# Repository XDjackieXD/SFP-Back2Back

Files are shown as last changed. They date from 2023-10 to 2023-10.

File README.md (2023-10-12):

# SFP+ Back2Back

This is a simple board to connect two SFP/SFP+ modules together.

So far it has only been tested with 10G fiber transceivers.
While it should work with other 1G and 10G (and maybe even 25G) modules and DACs too, I have not tested it with those (and I know that DACs tend to be more of an issue with such passive adapters/extenders).

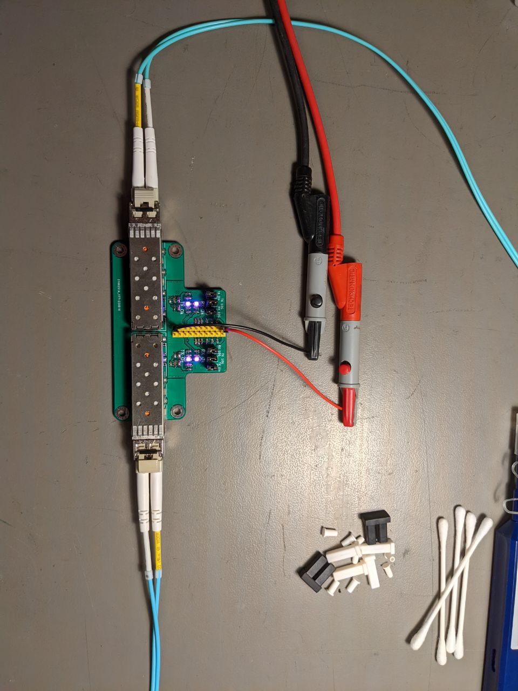
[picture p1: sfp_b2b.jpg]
The SFP+ Back2Back board connected to a power supply and two multimode SFP+ transceivers SFP+ Back2Back


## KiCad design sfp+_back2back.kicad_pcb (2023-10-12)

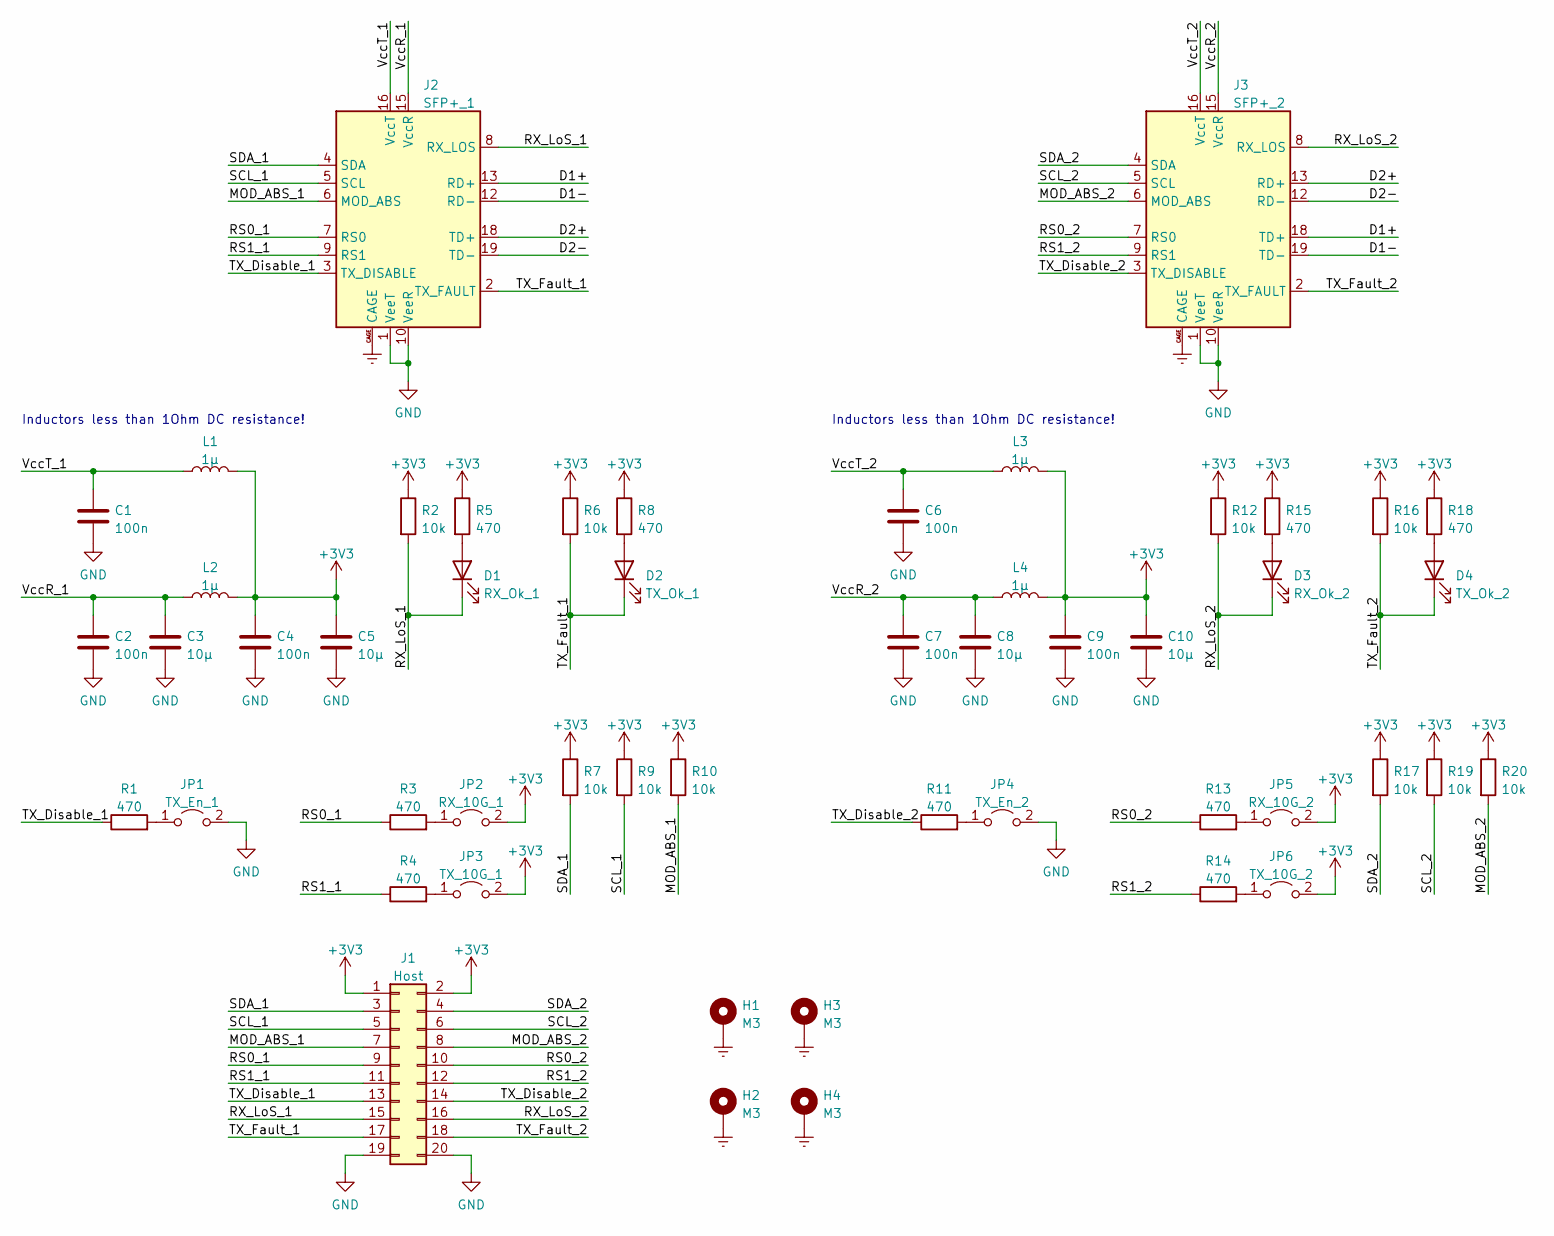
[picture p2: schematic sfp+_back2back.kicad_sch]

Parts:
C1, C2, C4, C6, C7, C9: 100n; C_0603_1608Metric_Pad1.08x0.95mm_HandSolder
C3, C5, C8, C10: 10µ; C_0805_2012Metric_Pad1.18x1.45mm_HandSolder
D1: RX_Ok_1; LED_0805_2012Metric_Pad1.15x1.40mm_HandSolder
D2: TX_Ok_1; LED_0805_2012Metric_Pad1.15x1.40mm_HandSolder
D3: RX_Ok_2; LED_0805_2012Metric_Pad1.15x1.40mm_HandSolder
D4: TX_Ok_2; LED_0805_2012Metric_Pad1.15x1.40mm_HandSolder
H1, H2, H3, H4: M3; MountingHole_3.2mm_M3_Pad_Via
J1: Host; PinHeader_2x10_P2.54mm_Vertical
J2: SFP+_1; Connector_SFP_and_Cage
J3: SFP+_2; Connector_SFP_and_Cage
JP1: TX_En_1; PinHeader_1x02_P2.54mm_Vertical
JP2: RX_10G_1; PinHeader_1x02_P2.54mm_Vertical
JP3: TX_10G_1; PinHeader_1x02_P2.54mm_Vertical
JP4: TX_En_2; PinHeader_1x02_P2.54mm_Vertical
JP5: RX_10G_2; PinHeader_1x02_P2.54mm_Vertical
JP6: TX_10G_2; PinHeader_1x02_P2.54mm_Vertical
L1, L2, L3, L4: 1µ; L_0805_2012Metric_Pad1.15x1.40mm_HandSolder
R1, R3, R4, R5, R8, R11, R13, R14, R15, R18: 470; R_0603_1608Metric_Pad0.98x0.95mm_HandSolder
R2, R6, R7, R9, R10, R12, R16, R17, R19, R20: 10k; R_0603_1608Metric_Pad0.98x0.95mm_HandSolder

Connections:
+3V3: C4.1, C5.1, C9.1, C10.1, J1.1, J1.2, JP2.2 (B), JP3.2 (B), JP5.2 (B), JP6.2 (B), L1.2, L2.2, L3.2, L4.2, R2.1, R5.1, R6.1, R7.1, R8.1, R9.1, R10.1, R12.1, R15.1, R16.1, R17.1, R18.1, R19.1, R20.1
/D1+: J2.13 (RD+), J3.18 (TD+)
/D1-: J2.12 (RD-), J3.19 (TD-)
/D2+: J2.18 (TD+), J3.13 (RD+)
/D2-: J2.19 (TD-), J3.12 (RD-)
/MOD_ABS_1: J1.7, J2.6 (MOD_ABS), R10.2
/MOD_ABS_2: J1.8, J3.6 (MOD_ABS), R20.2
/RS0_1: J1.9, J2.7 (RS0), R3.1
/RS0_2: J1.10, J3.7 (RS0), R13.1
/RS1_1: J1.11, J2.9 (RS1), R4.1
/RS1_2: J1.12, J3.9 (RS1), R14.1
/RX_LoS_1: D1.1 (K), J1.15, J2.8 (RX_LOS), R2.2
/RX_LoS_2: D3.1 (K), J1.16, J3.8 (RX_LOS), R12.2
/SCL_1: J1.5, J2.5 (SCL), R9.2
/SCL_2: J1.6, J3.5 (SCL), R19.2
/SDA_1: J1.3, J2.4 (SDA), R7.2
/SDA_2: J1.4, J3.4 (SDA), R17.2
/TX_Disable_1: J1.13, J2.3 (TX_DISABLE), R1.1
/TX_Disable_2: J1.14, J3.3 (TX_DISABLE), R11.1
/TX_Fault_1: D2.1 (K), J1.17, J2.2 (TX_FAULT), R6.2
/TX_Fault_2: D4.1 (K), J1.18, J3.2 (TX_FAULT), R16.2
/VccR_1: C2.1, C3.1, J2.15 (VccR), L2.1
/VccR_2: C7.1, C8.1, J3.15 (VccR), L4.1
/VccT_1: C1.1, J2.16 (VccT), L1.1
/VccT_2: C6.1, J3.16 (VccT), L3.1
Earth: H1.1, H2.1, H3.1, H4.1, J2.CAGE, J3.CAGE
GND: C1.2, C2.2, C3.2, C4.2, C5.2, C6.2, C7.2, C8.2, C9.2, C10.2, J1.19, J1.20, J2.1 (VeeT), J2.10 (VeeR), J2.11 (VeeR), J2.14 (VeeR), J2.17 (VeeT), J2.20 (VeeT), J3.1 (VeeT), J3.10 (VeeR), J3.11 (VeeR), J3.14 (VeeR), J3.17 (VeeT), J3.20 (VeeT), JP1.2 (B), JP4.2 (B)
unnamed: D1.2 (A), R5.2
unnamed: D2.2 (A), R8.2
unnamed: D3.2 (A), R15.2
unnamed: D4.2 (A), R18.2
unnamed: JP1.1 (A), R1.2
unnamed: JP2.1 (A), R3.2
unnamed: JP3.1 (A), R4.2
unnamed: JP4.1 (A), R11.2
unnamed: JP5.1 (A), R13.2
unnamed: JP6.1 (A), R14.2

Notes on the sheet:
Inductors less than 1Ohm DC resistance!

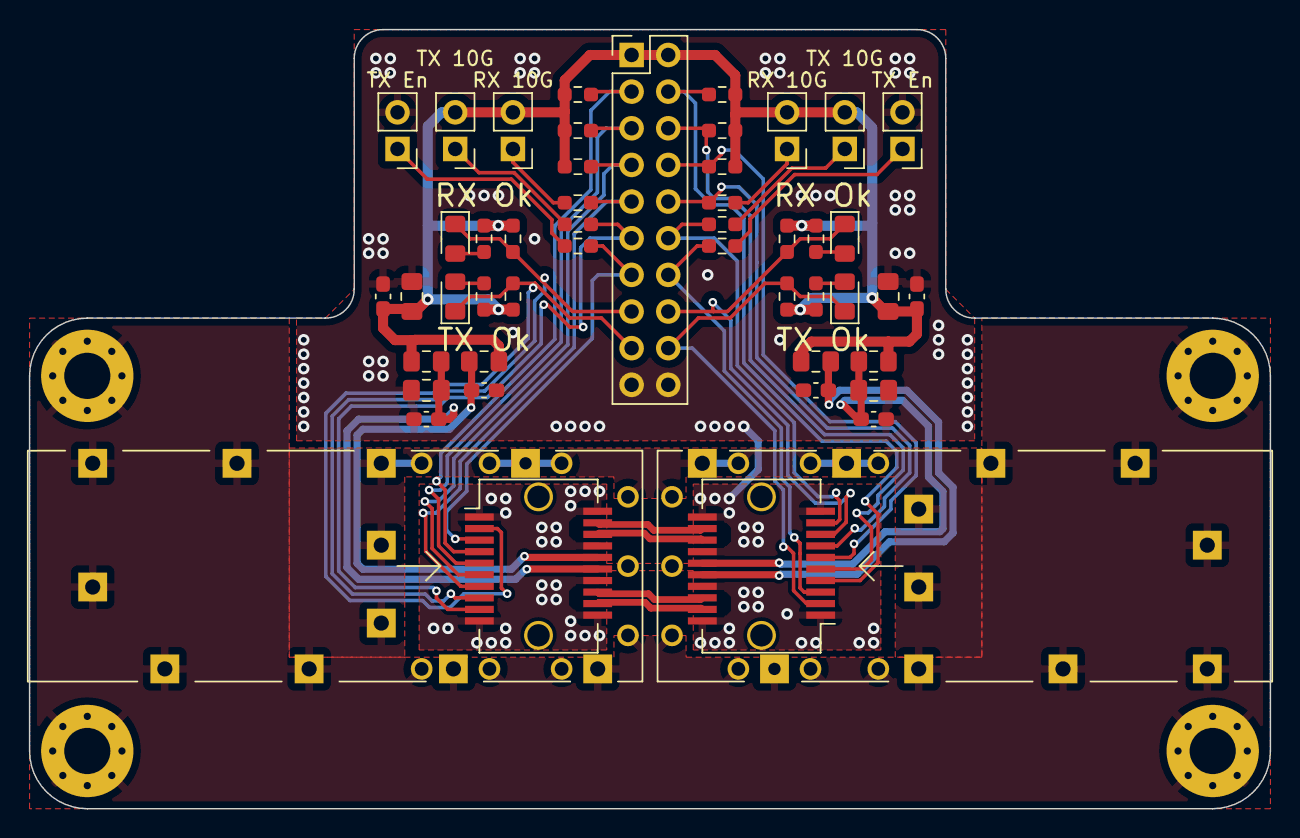
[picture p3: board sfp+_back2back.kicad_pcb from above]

Board: 2 copper layers, 86.0 x 54.0 mm, 51 parts (0 on the bottom side), 37 nets.
